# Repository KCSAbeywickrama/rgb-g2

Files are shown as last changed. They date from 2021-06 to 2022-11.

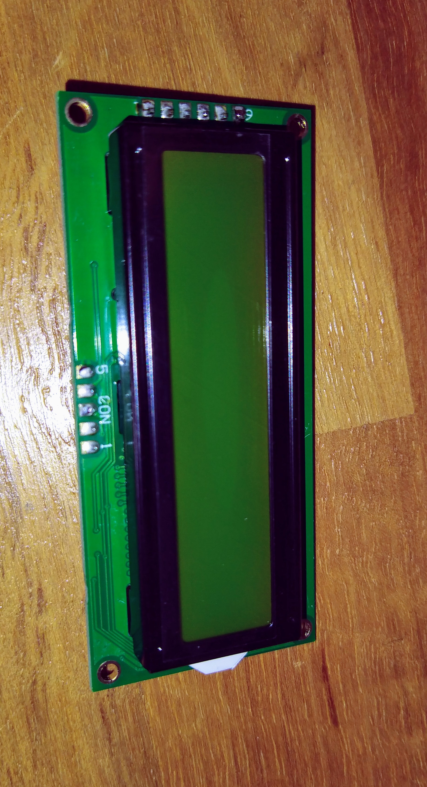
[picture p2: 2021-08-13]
enclosure/external parts/lcd/LCD Module 16x2.jpg

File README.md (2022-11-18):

**LEN1093 Laboratory Practice - I : RGB Color Sensor Project**

A colour sensing device is made using the RGB model approach. This device has three operational modes. Calibration mode, Sensor mode and Given value RGB mode. The calibration mode is to calibrate the device before the test run and this is done in real-time using only three colours. The goal of the Sensor mode is to identify the red, green, blue content in the colour of a given surface and display them using an LCD. In given value RGB mode
a keypad is used to get user inputs and light is illuminated according to those inputs. This colour sensor is developed without using any third-party libraries and only using one PWM pin in the microcontroller to control an RGB LED. We explored different algorithms to achieve high accuracy and finally ended up with a simple endpoint method algorithm. An end product is made including the custom PCB design and a user-friendly 3D enclosure.

**Group Members**

<pre>
+-----------+----------------------+----------------+  
|   Index   |         Name         |    Branches    |  
+-----------+----------------------+----------------+
|  190012X  | Abeysinghe A.L.R     | 12X, enclosure |
|  190014F  | Abeysinghe W.A.M.S.Y | 14F, pcb       |  
|  190018V  | Abeywickrama K.C.S.  | 18V, pcb       |  
|  190021A  | Adikari A.M.A.D.     | 21A, enclosure |  
+-----------+----------------------+----------------+  
</pre>

https://user-images.githubusercontent.com/81417619/202612575-ead0735a-a69e-47e2-82ca-92c3c0942de2.mp4

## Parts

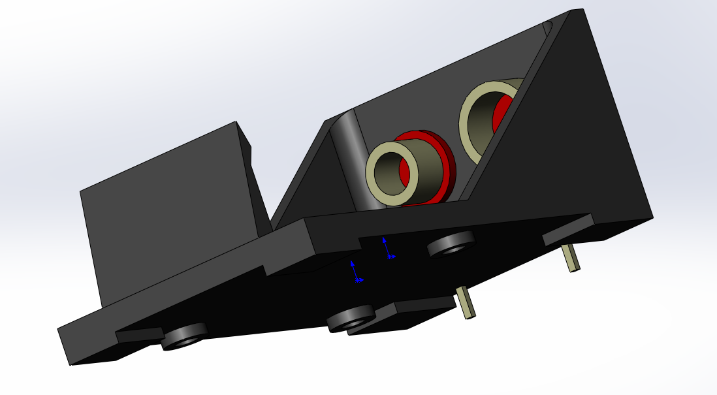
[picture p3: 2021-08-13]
enclosure/external parts/battery holder/Renderings/Безымянный.png

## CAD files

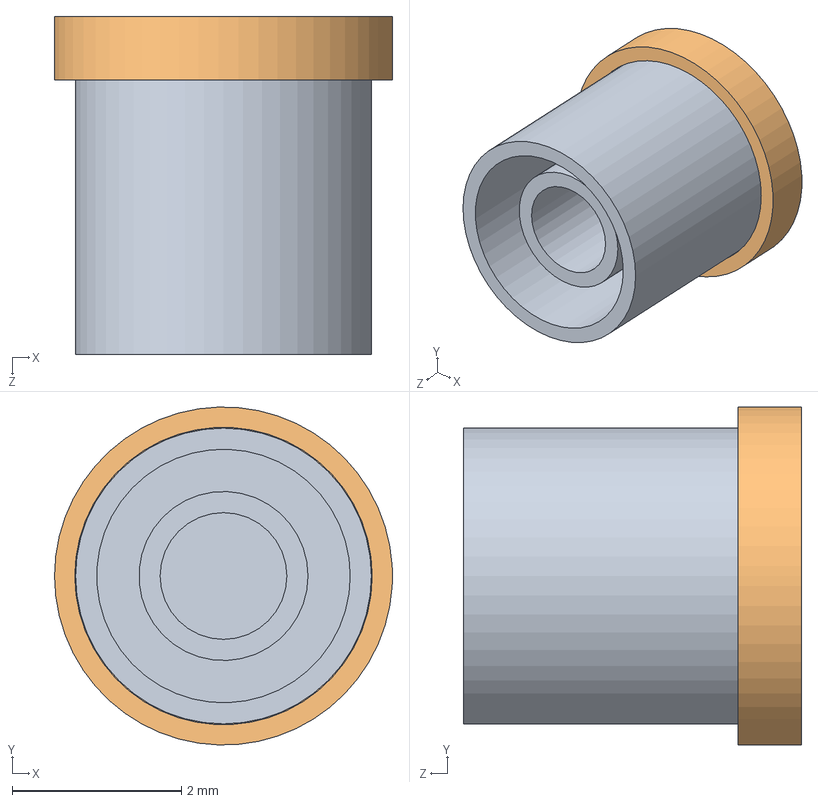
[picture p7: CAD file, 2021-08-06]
enclosure/12X/Sensor_full.SLDASM
4.00 x 4.00 x 4.00 mm
sensor_model_1_p1
sensor_model_1_p2

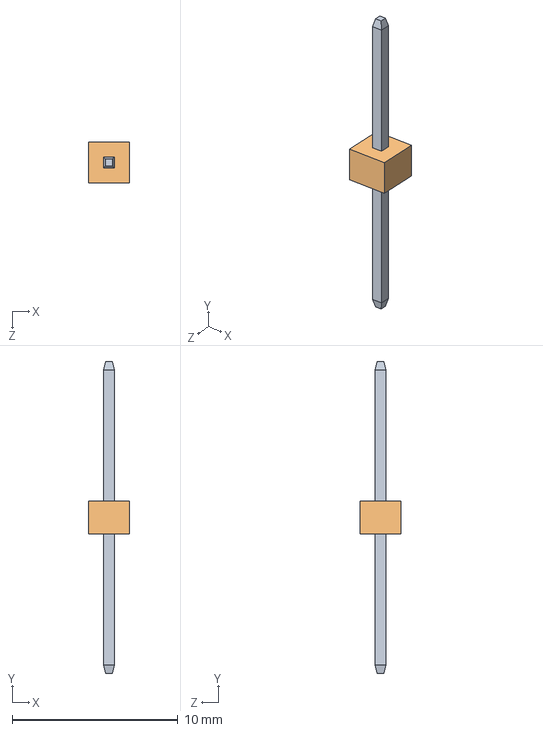
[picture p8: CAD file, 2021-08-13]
enclosure/external parts/jumper/Jumper.SLDASM
2.50 x 18.8 x 2.50 mm
Pin
Socket

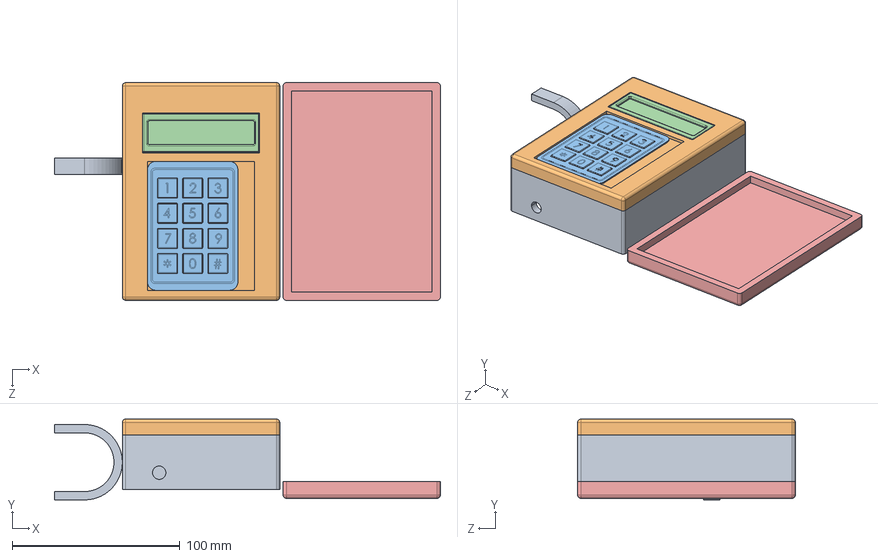
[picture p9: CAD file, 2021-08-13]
enclosure/enclosure parts/enclosure assembly.SLDASM
230.4 x 48.2 x 130.0 mm
middle_from_step
UPPER__FROM_STEP
keypad
LCDScreen
Part1^enclosure assembly

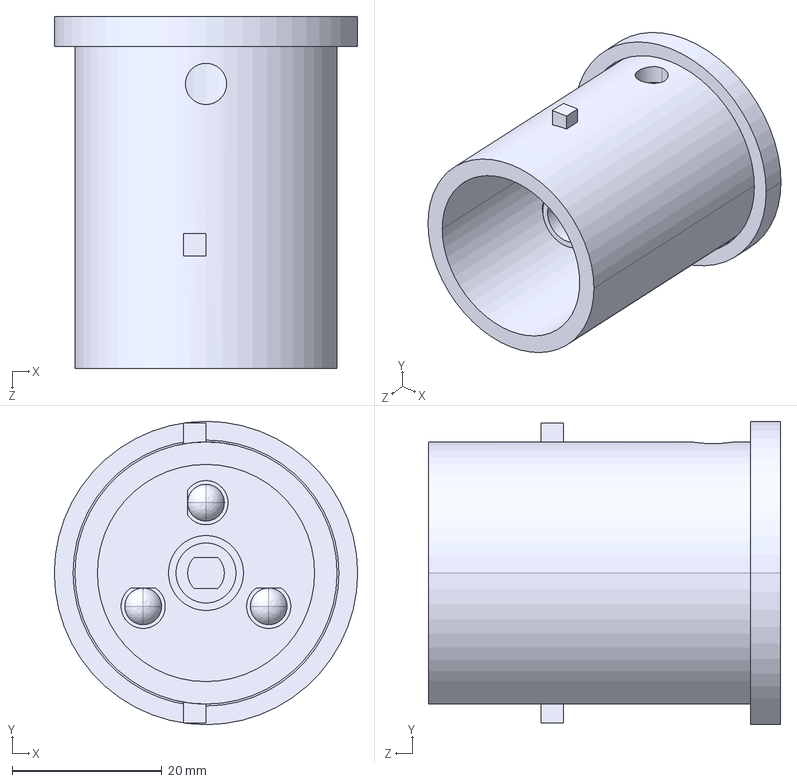
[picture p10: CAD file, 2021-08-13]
enclosure/Sensor/Sensor_full(final).STEP
40.5 x 40.5 x 47.0 mm
sensor_body
Resistor_10K_Ohm_tol1pct_0,25W__07,62.step x 2
LED_5mm_white_TH.step x 3
Extruded.step
Cylinder.step
Cylinder-0.step
Sensor_Top

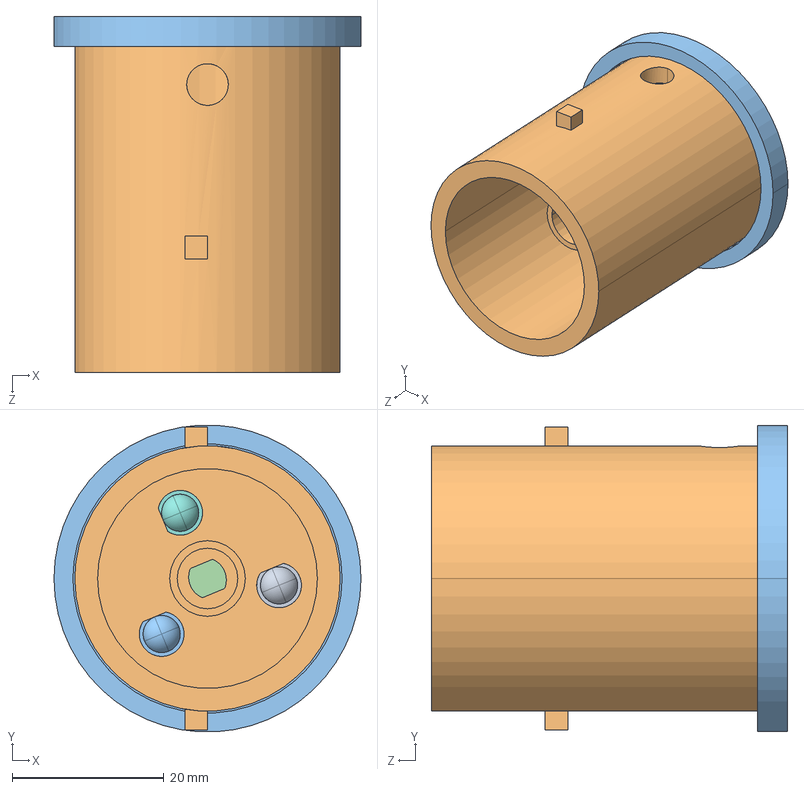
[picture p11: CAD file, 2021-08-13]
enclosure/Sensor/Sensor_full.SLDASM
40.5 x 40.4 x 47.0 mm
Resistor_10K_Ohm_tol1pct_0,25W__07,62.step^R7.step_PCB_Sensor (2).step_Sensor_full (1)_Sensor_full
LED_5mm_white_TH.step^D1.step_PCB_Sensor (2).step_Sensor_full (1)_Sensor_full
Extruded.step^5044068176.step_R9.step_PCB_Sensor (2).step_Sensor_full (1)_Sensor_full
Cylinder.step^6007015744.step_R9.step_PCB_Sensor (2).step_Sensor_full (1)_Sensor_full
Cylinder-0.step^5044512256.step_R9.step_PCB_Sensor (2).step_Sensor_full (1)_Sensor_full
Resistor_10K_Ohm_tol1pct_0,25W__07,62.step^R8.step_PCB_Sensor (2).step_Sensor_full (1)_Sensor_full
LED_5mm_white_TH.step^D3.step_PCB_Sensor (2).step_Sensor_full (1)_Sensor_full
LED_5mm_white_TH.step^D2.step_PCB_Sensor (2).step_Sensor_full (1)_Sensor_full
sensor_body^Sensor_full (1)_Sensor_full
Sensor_Top^Sensor_full (1)_Sensor_full

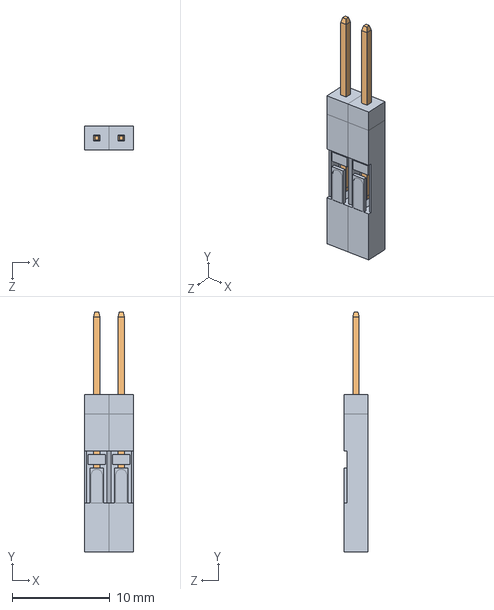
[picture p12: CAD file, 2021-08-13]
enclosure/external parts/jumper/Patterned.SLDASM
5.00 x 24.5 x 2.50 mm
Socket x 4
Pin x 2

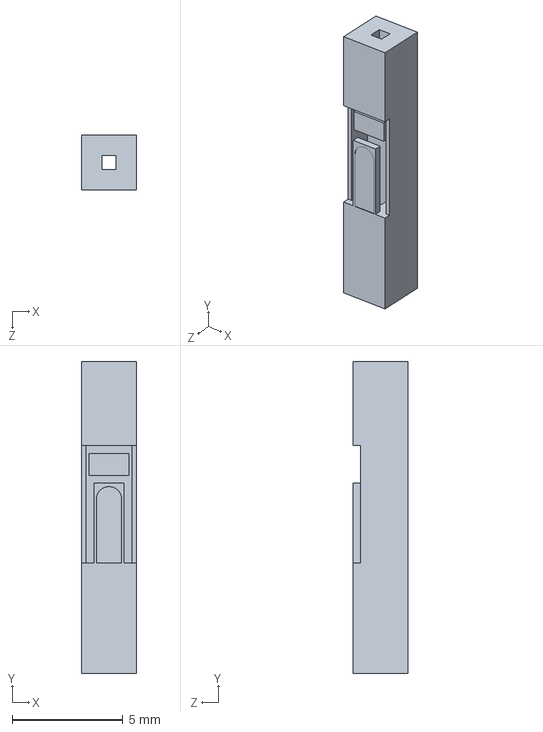
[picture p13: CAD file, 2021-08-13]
enclosure/external parts/jumper/Converted/STEP/Socket_lcd.SLDASM
2.50 x 14.1 x 2.50 mm

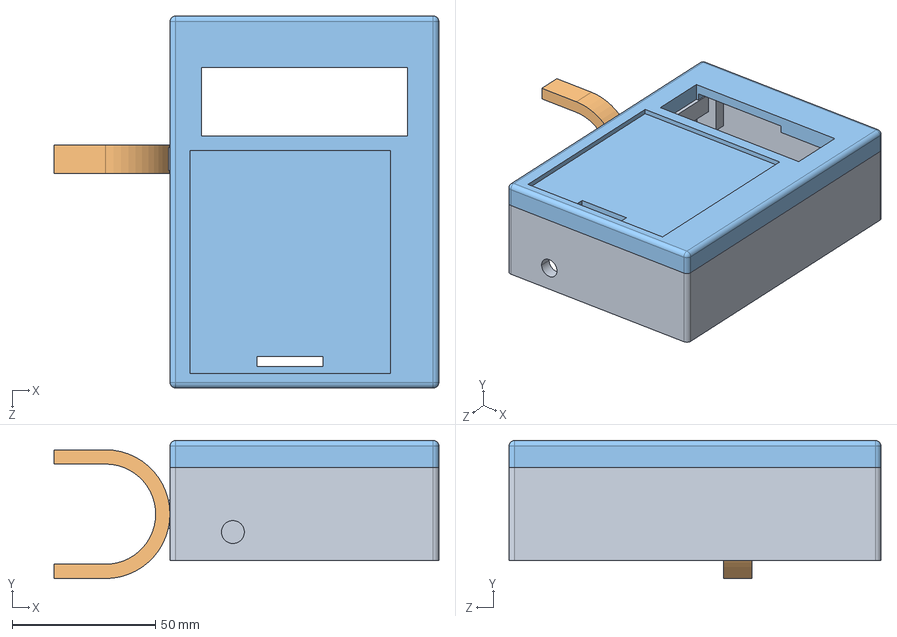
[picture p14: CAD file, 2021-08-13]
enclosure/model_2_assembly(up+mid)_stp.STEP
134.5 x 48.2 x 130.0 mm
Model_2_middle
Model_2_upper

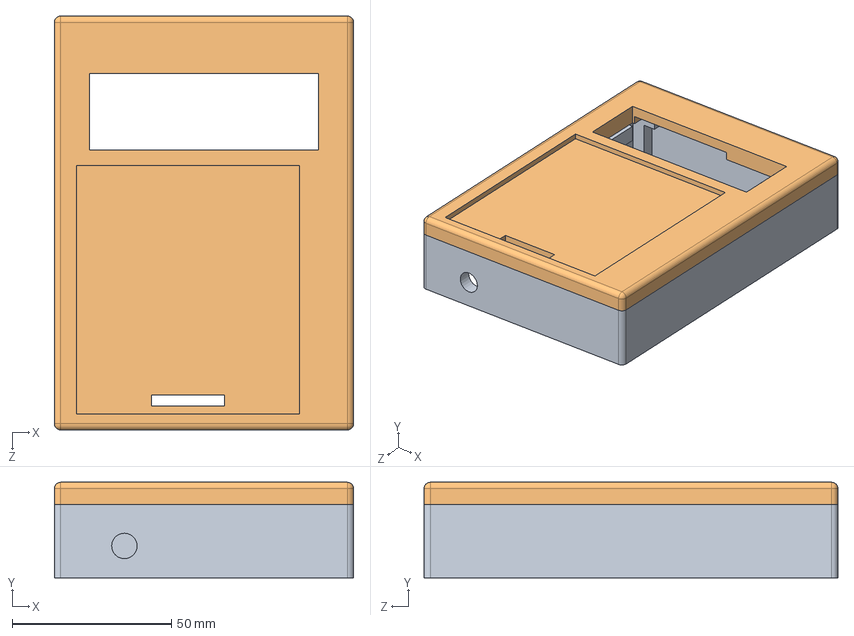
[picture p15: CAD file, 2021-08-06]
enclosure/enclosure_missed/model_2_assembly(up+mid).SLDASM
94.0 x 30.0 x 130.0 mm
Model_2_middle
Model_2_upper

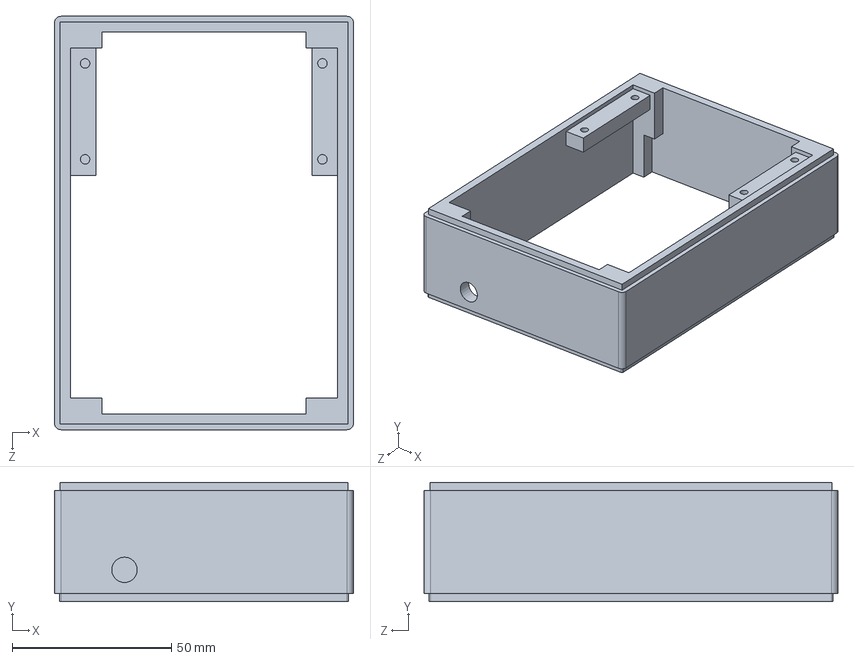
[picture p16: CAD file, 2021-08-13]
enclosure/enclosure parts/middle_without_hanger.SLDPRT
94.0 x 37.5 x 130.0 mm

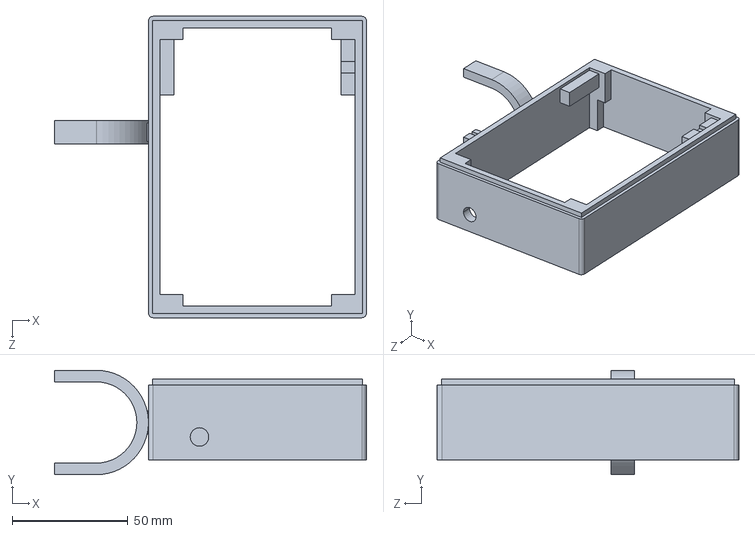
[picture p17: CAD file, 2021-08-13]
enclosure/enclosure_missed/middle_from_step.SLDPRT
134.5 x 45.0 x 130.0 mm

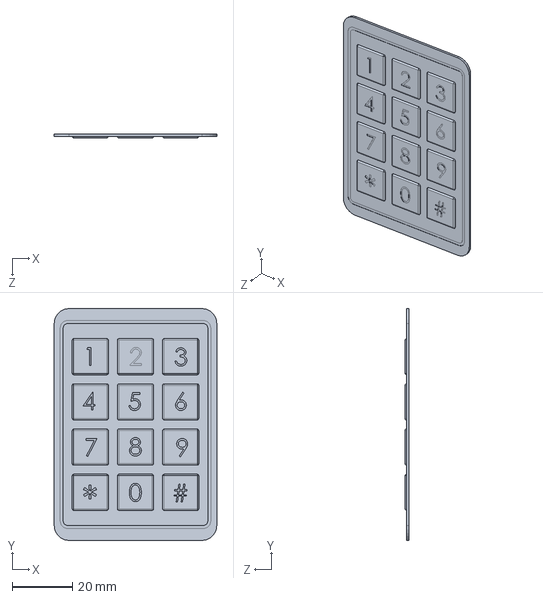
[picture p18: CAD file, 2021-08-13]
enclosure/enclosure_missed/parts/keypad/keypad_noColor.SLDPRT
54.0 x 77.0 x 1.31 mm

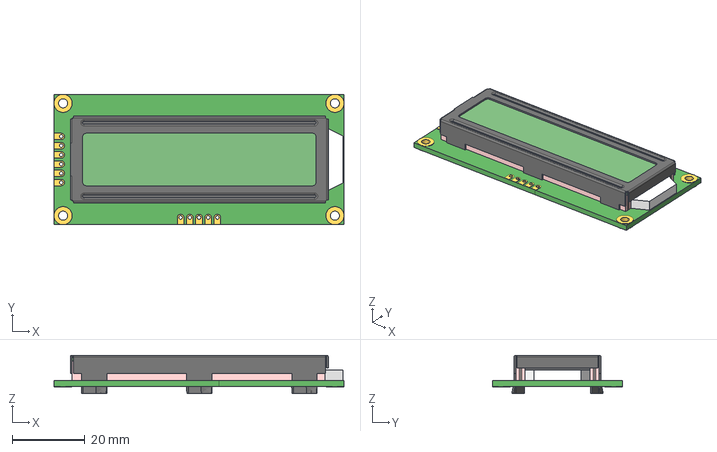
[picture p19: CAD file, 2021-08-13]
enclosure/enclosure_missed/parts/lcd/RSI1602-00.stp
80.0 x 36.0 x 10.6 mm

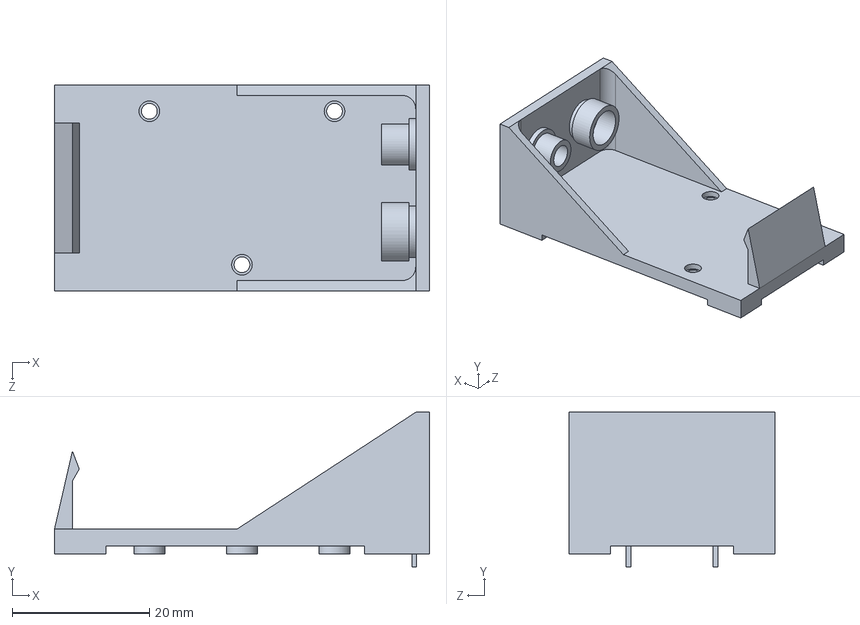
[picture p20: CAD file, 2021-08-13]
enclosure/external parts/battery holder/BATTARY HOLDER.STEP
54.6 x 22.5 x 30.0 mm

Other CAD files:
enclosure/Sensor/Sensor_full (1).STEP
enclosure/12X/sensor_model_1_p1.SLDPRT
enclosure/12X/sensor_model_1_p2.SLDPRT
enclosure/21A_upper.SLDPRT
enclosure/Model_2_middle.SLDPRT
enclosure/Model_2_middle_stp.STEP
enclosure/Model_2_upper.SLDPRT
enclosure/Model_2_upper_stp.STEP
enclosure/Sensor/PCB_Sensor (2).step
enclosure/Sensor/Sensor_Top.STEP
enclosure/Sensor/Sensor_full(final).SLDASM
enclosure/Sensor/sensor_body.STEP
enclosure/enclosure parts/Model_2_middle.SLDPRT
enclosure/enclosure parts/Model_2_upper.SLDPRT
enclosure/enclosure parts/UPPER__FROM_STEP.SLDPRT
enclosure/enclosure parts/bottom_part.SLDPRT
enclosure/enclosure parts/circular_leg.SLDPRT
enclosure/enclosure parts/middle_from_step.SLDPRT
enclosure/enclosure parts/middle_part_from_step.x_t
enclosure/enclosure parts/model_1.SLDPRT
enclosure/enclosure parts/sensor_closer.SLDPRT
enclosure/enclosure parts/sensor_model1.SLDPRT
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

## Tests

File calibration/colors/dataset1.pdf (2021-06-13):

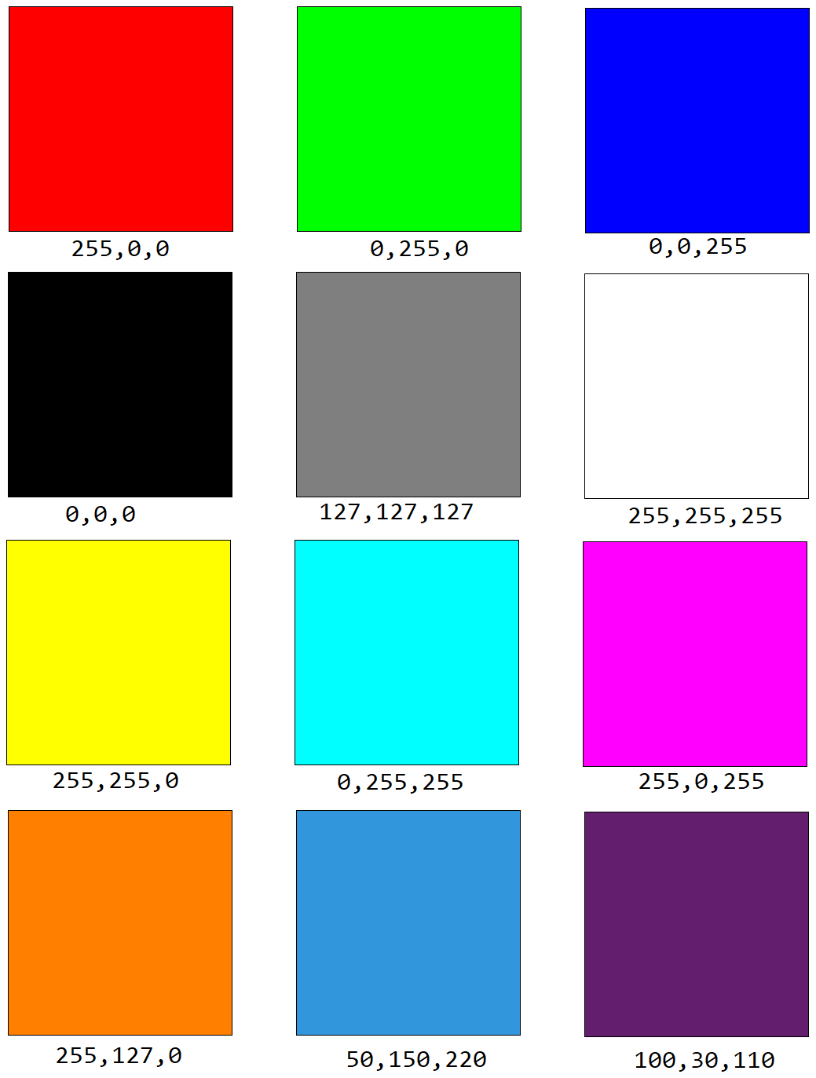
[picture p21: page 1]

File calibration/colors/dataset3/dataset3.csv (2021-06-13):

r | g | b | r | g | r | "-b" | "-b" | g
255 | 255 | 255 | 255 | 255 | 255 | -255 | -255 | 255
0 | 0 | 0 | 0 | 0 | 0 | 0 | 0 | 0
255 | 0 | 0 | 255 | 0 | 255 | 0 | 0 | 0
0 | 255 | 0 | 0 | 255 | 0 | 0 | 0 | 255
0 | 0 | 255 | 0 | 0 | 0 | -255 | -255 | 0
255 | 192 | 192 | 255 | 192 | 255 | -192 | -192 | 192
255 | 128 | 128 | 255 | 128 | 255 | -128 | -128 | 128
255 | 64 | 64 | 255 | 64 | 255 | -64 | -64 | 64
204 | 0 | 0 | 204 | 0 | 204 | 0 | 0 | 0
153 | 0 | 0 | 153 | 0 | 153 | 0 | 0 | 0
102 | 0 | 0 | 102 | 0 | 102 | 0 | 0 | 0
51 | 0 | 0 | 51 | 0 | 51 | 0 | 0 | 0
192 | 255 | 192 | 192 | 255 | 192 | -192 | -192 | 255
128 | 255 | 128 | 128 | 255 | 128 | -128 | -128 | 255
64 | 255 | 64 | 64 | 255 | 64 | -64 | -64 | 255
0 | 204 | 0 | 0 | 204 | 0 | 0 | 0 | 204
0 | 153 | 0 | 0 | 153 | 0 | 0 | 0 | 153
0 | 102 | 0 | 0 | 102 | 0 | 0 | 0 | 102
0 | 51 | 0 | 0 | 51 | 0 | 0 | 0 | 51
192 | 192 | 255 | 192 | 192 | 192 | -255 | -255 | 192
128 | 128 | 255 | 128 | 128 | 128 | -255 | -255 | 128
64 | 64 | 255 | 64 | 64 | 64 | -255 | -255 | 64
0 | 0 | 204 | 0 | 0 | 0 | -204 | -204 | 0
0 | 0 | 153 | 0 | 0 | 0 | -153 | -153 | 0
0 | 0 | 102 | 0 | 0 | 0 | -102 | -102 | 0
0 | 0 | 51 | 0 | 0 | 0 | -51 | -51 | 0
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

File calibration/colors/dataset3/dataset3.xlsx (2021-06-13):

r | g | b | r | g | r | "-b" | "-b" | g
255 | 255 | 255 | 255 | 255 | 255 | -255 | -255 | 255
0 | 0 | 0 | 0 | 0 | 0 | 0 | 0 | 0
255 | 0 | 0 | 255 | 0 | 255 | 0 | 0 | 0
0 | 255 | 0 | 0 | 255 | 0 | 0 | 0 | 255
0 | 0 | 255 | 0 | 0 | 0 | -255 | -255 | 0
255 | 192 | 192 | 255 | 192 | 255 | -192 | -192 | 192
255 | 128 | 128 | 255 | 128 | 255 | -128 | -128 | 128
255 | 64 | 64 | 255 | 64 | 255 | -64 | -64 | 64
204 | 0 | 0 | 204 | 0 | 204 | 0 | 0 | 0
153 | 0 | 0 | 153 | 0 | 153 | 0 | 0 | 0
102 | 0 | 0 | 102 | 0 | 102 | 0 | 0 | 0
51 | 0 | 0 | 51 | 0 | 51 | 0 | 0 | 0
192 | 255 | 192 | 192 | 255 | 192 | -192 | -192 | 255
128 | 255 | 128 | 128 | 255 | 128 | -128 | -128 | 255
64 | 255 | 64 | 64 | 255 | 64 | -64 | -64 | 255
0 | 204 | 0 | 0 | 204 | 0 | 0 | 0 | 204
0 | 153 | 0 | 0 | 153 | 0 | 0 | 0 | 153
0 | 102 | 0 | 0 | 102 | 0 | 0 | 0 | 102
0 | 51 | 0 | 0 | 51 | 0 | 0 | 0 | 51
192 | 192 | 255 | 192 | 192 | 192 | -255 | -255 | 192
128 | 128 | 255 | 128 | 128 | 128 | -255 | -255 | 128
64 | 64 | 255 | 64 | 64 | 64 | -255 | -255 | 64
0 | 0 | 204 | 0 | 0 | 0 | -204 | -204 | 0
0 | 0 | 153 | 0 | 0 | 0 | -153 | -153 | 0
0 | 0 | 102 | 0 | 0 | 0 | -102 | -102 | 0
0 | 0 | 51 | 0 | 0 | 0 | -51 | -51 | 0
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

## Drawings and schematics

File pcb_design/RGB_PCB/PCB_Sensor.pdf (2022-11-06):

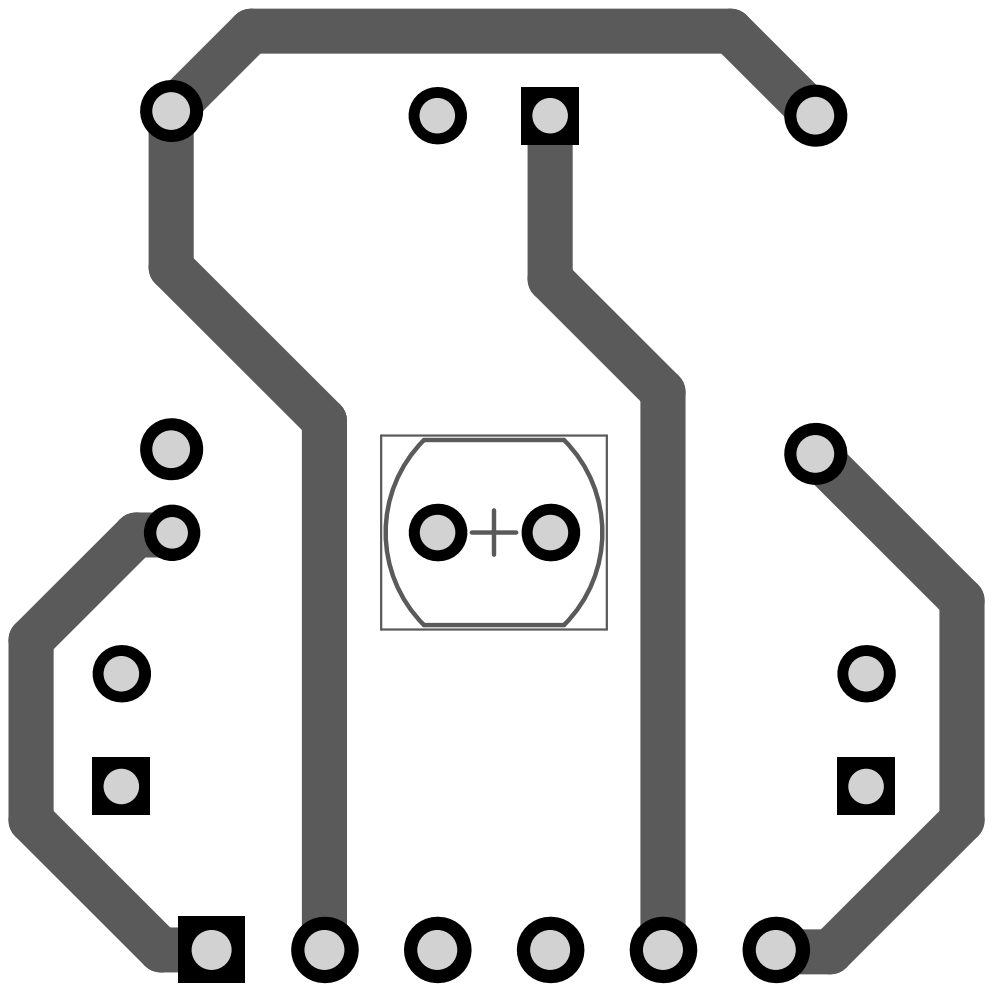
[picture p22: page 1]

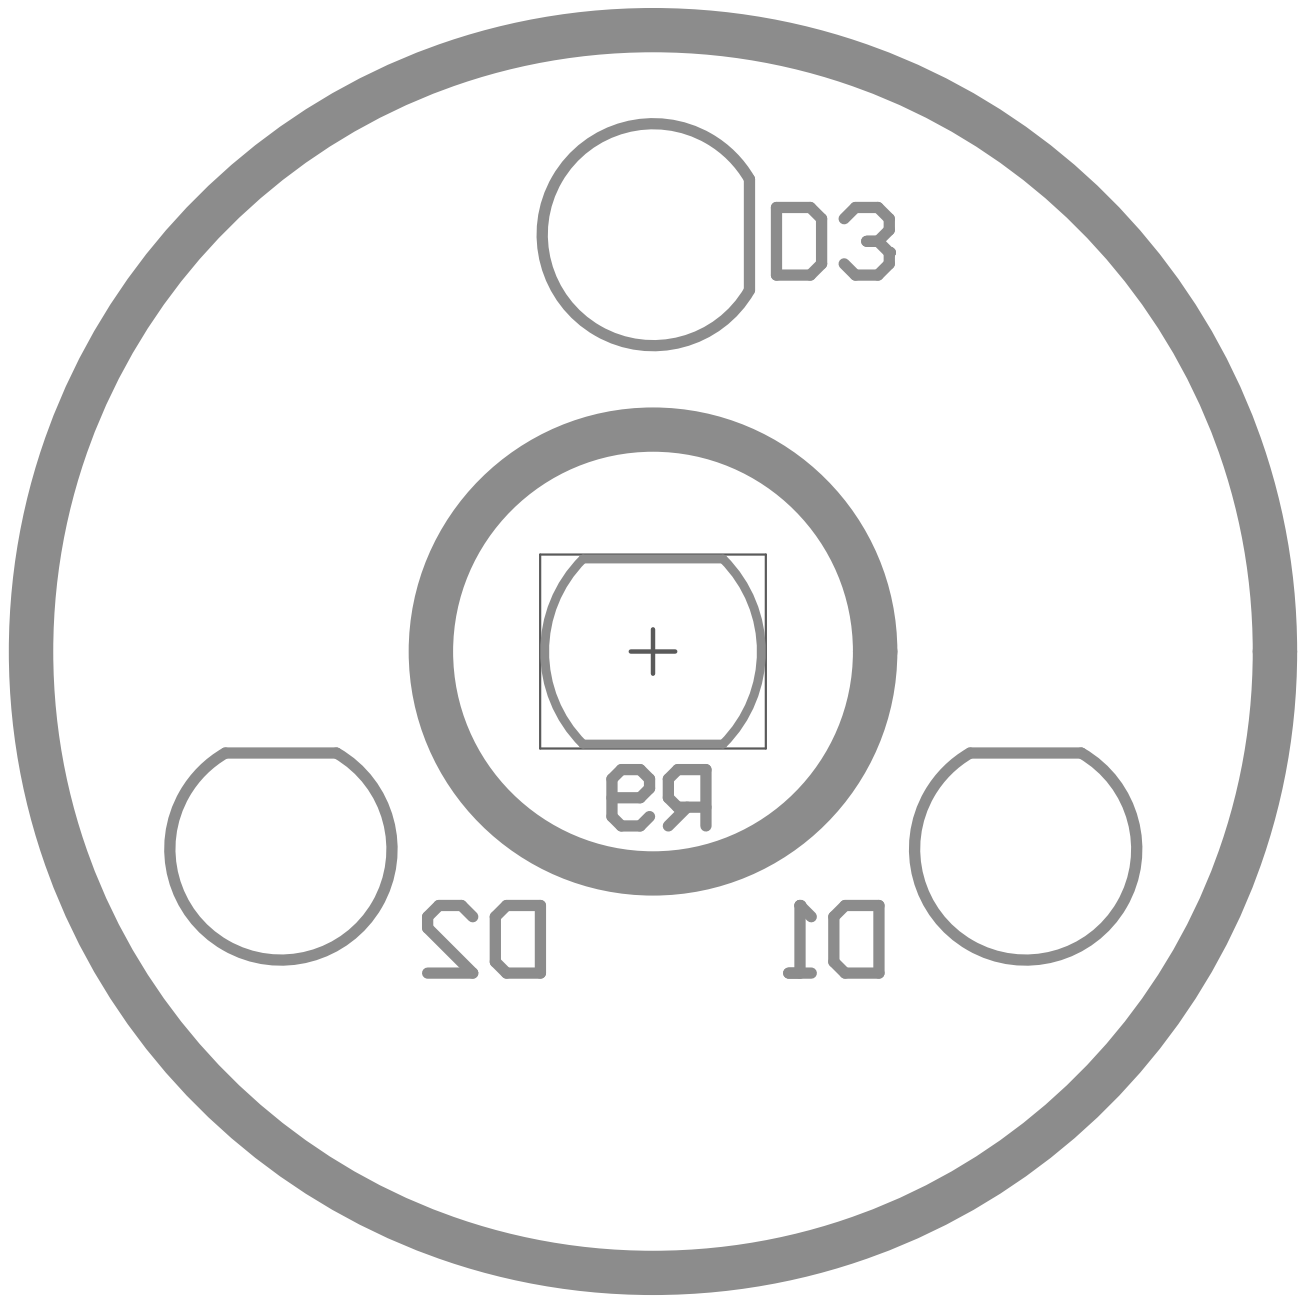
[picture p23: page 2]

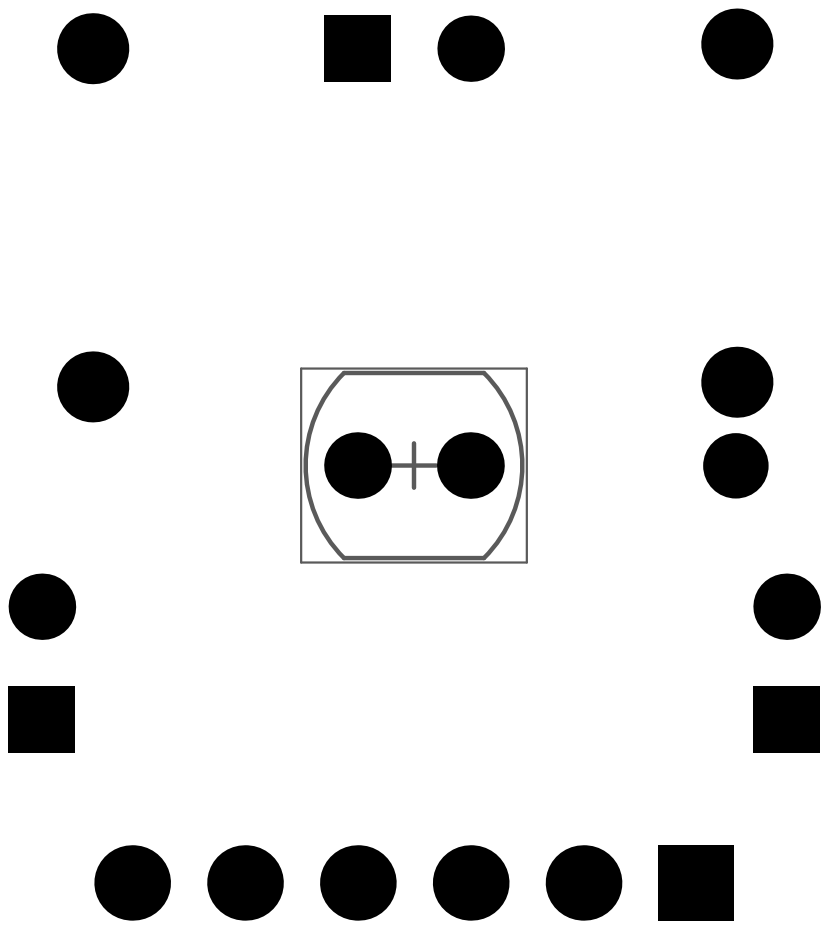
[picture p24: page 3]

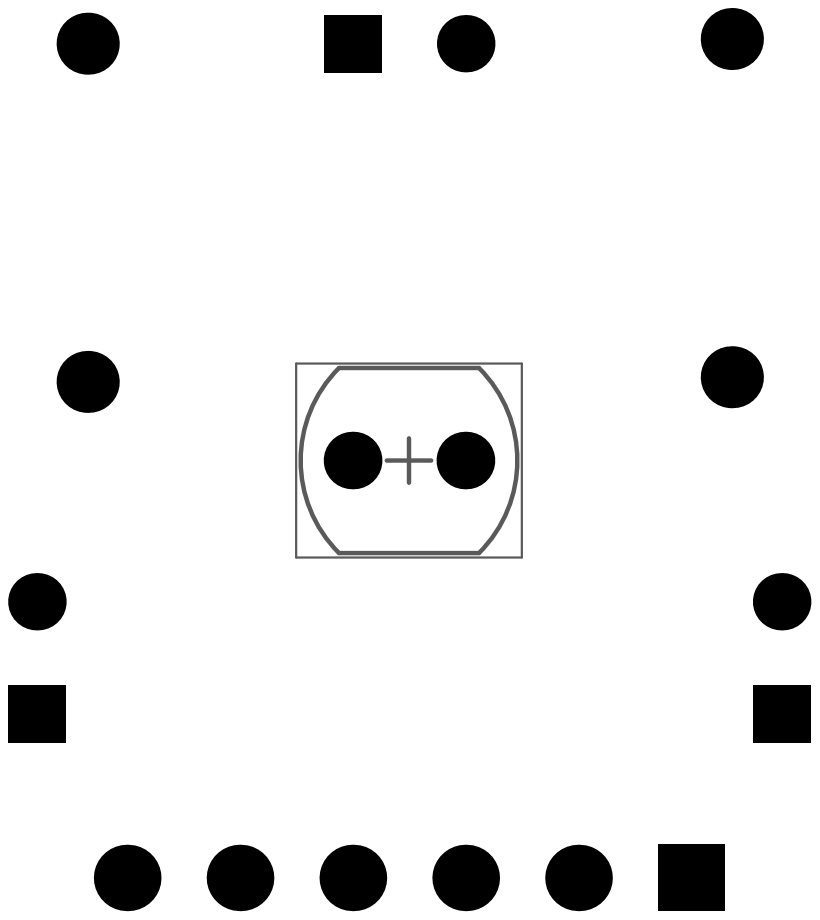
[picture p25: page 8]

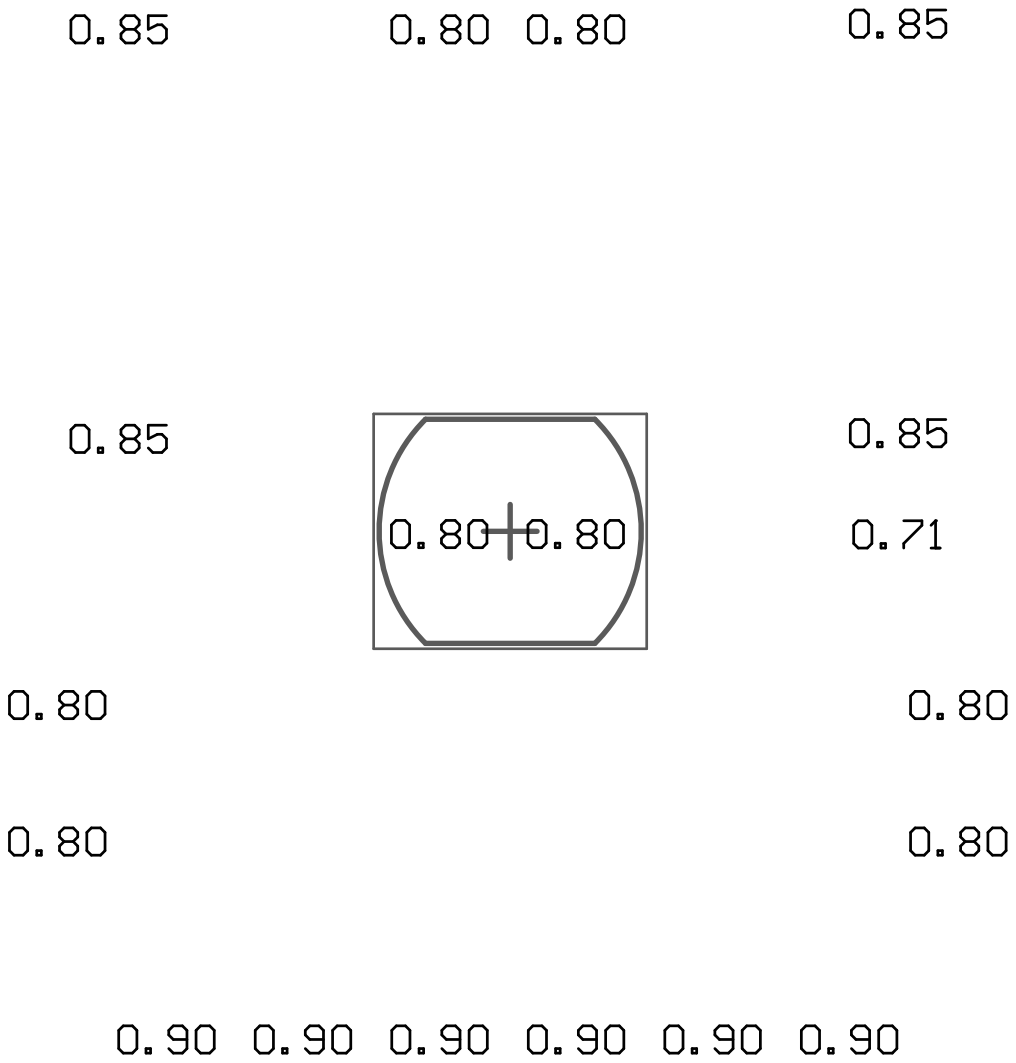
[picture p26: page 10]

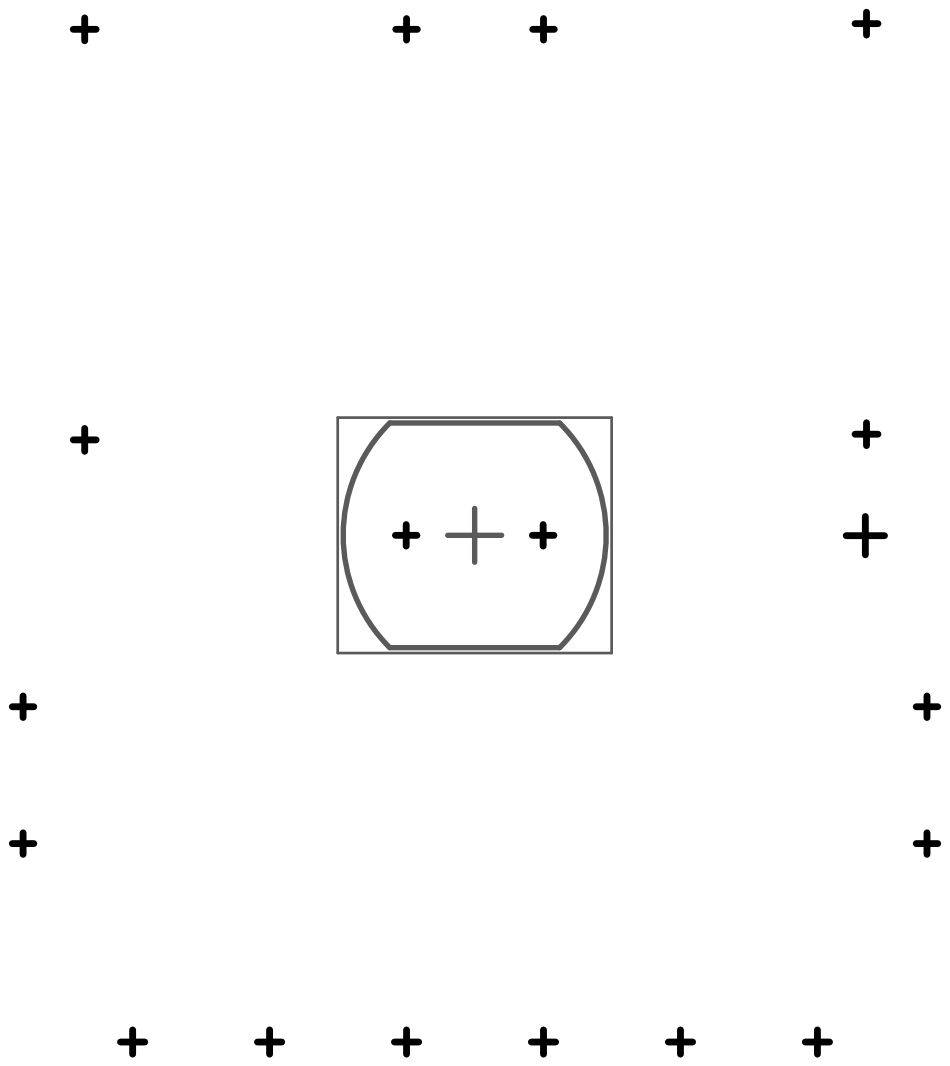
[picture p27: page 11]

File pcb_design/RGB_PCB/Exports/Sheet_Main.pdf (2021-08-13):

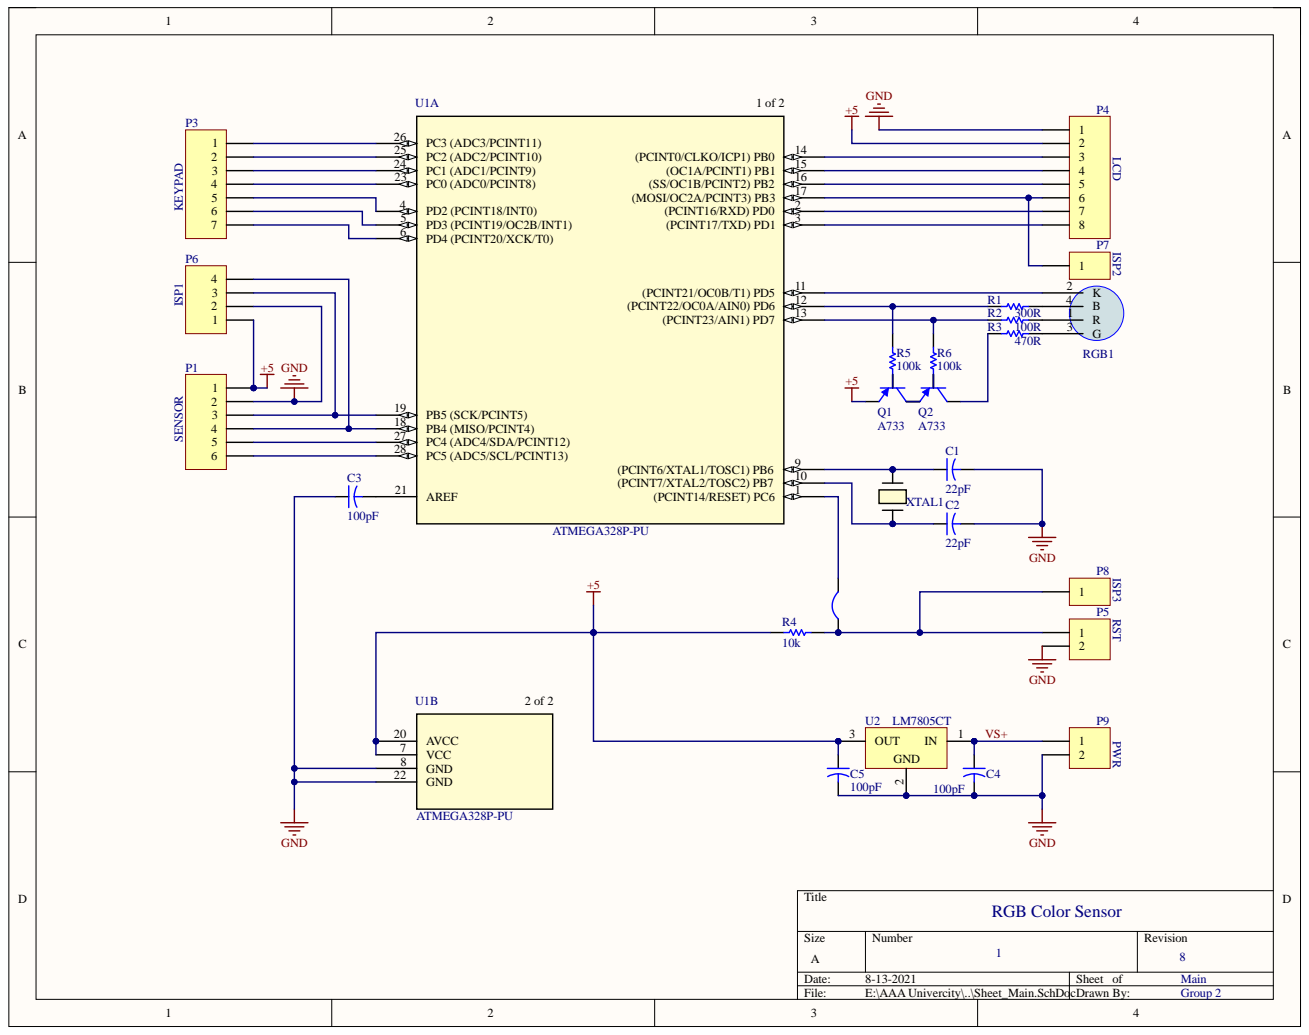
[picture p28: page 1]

PB4 (MISO/PCINT4) 18 PB5 (SCK/PCINT5) 19

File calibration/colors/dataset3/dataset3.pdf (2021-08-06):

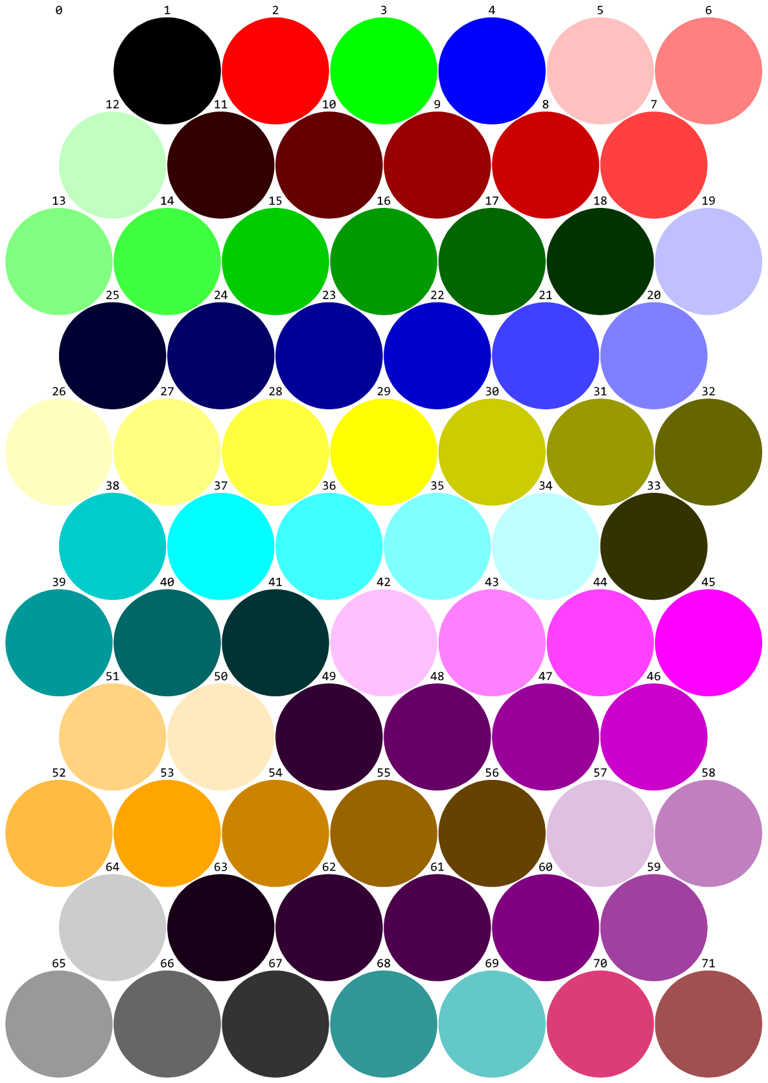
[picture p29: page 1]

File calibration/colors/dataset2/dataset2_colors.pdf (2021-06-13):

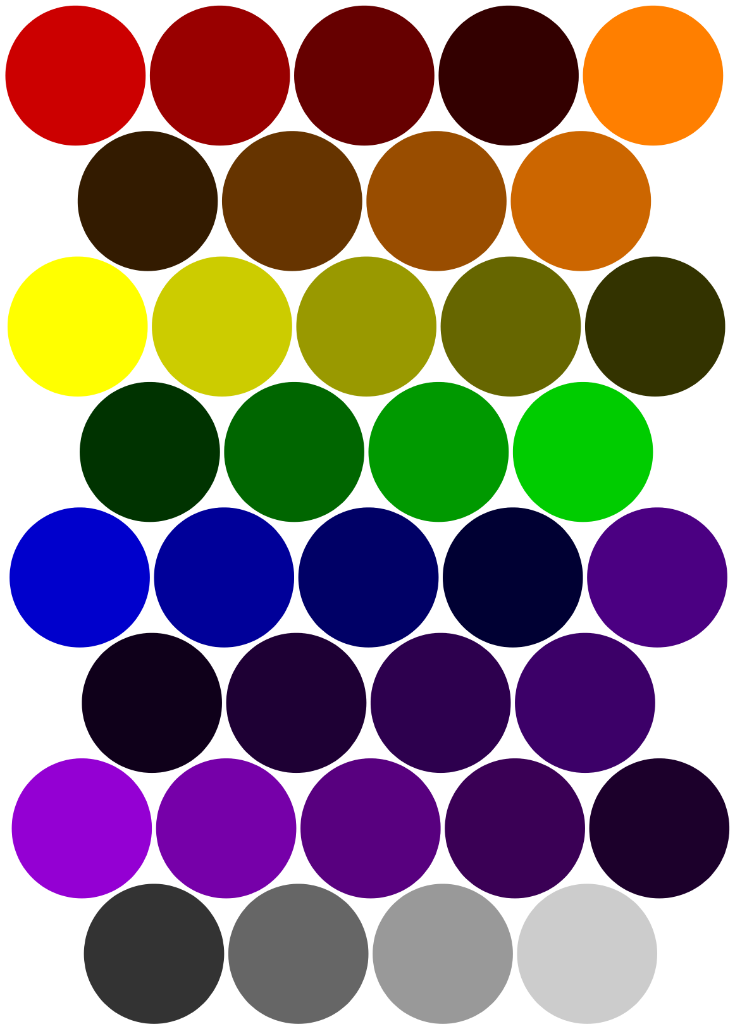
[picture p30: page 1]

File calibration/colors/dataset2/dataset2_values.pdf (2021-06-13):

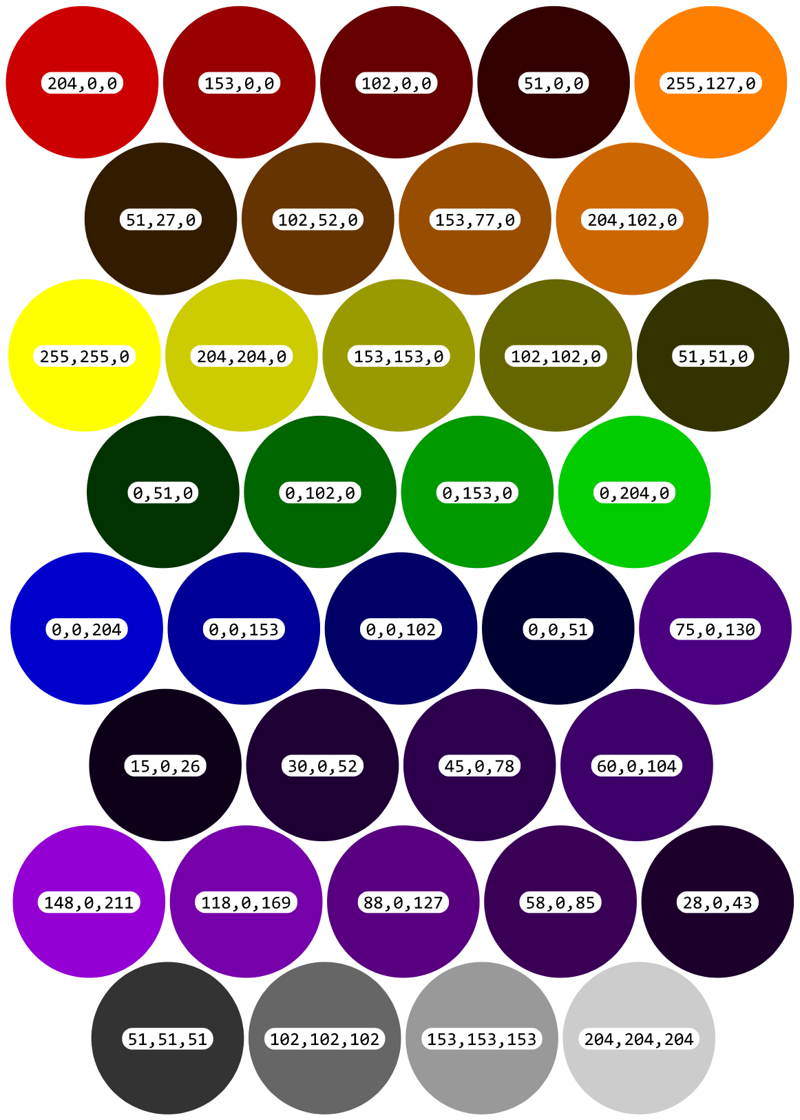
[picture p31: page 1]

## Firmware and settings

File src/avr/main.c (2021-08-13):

/*
* main.c
*
* Created: 6/12/2021 11:27:28 PM
* Author : Dulanjana
*/

#define F_CPU 16000000UL

#include <avr/io.h>
#include <util/delay.h>
#include "cores/lcd.h"
#include "cores/keypad.h"
#include "cores/pwm.h"
#include "cores/calib.h"
#include "cores/sensor.h"

uint16_t reading[3]; //sensor readings
uint8_t rgb[3];		 //rgb values
char *rgb_str[3]={"RED = ","GREEN = ","BLUE = "};

//declaring fucnitons for modes
void sensor_mode();
void calib_mode();
void read_mode();
void rgb_mode();


int main(void)
{
	//init cores
	lcd_init();	
	keypad_init();
	sensor_init();
	pwm_init();
	
	//display a startup message
	lcd_clear();
	lcd_string("RGB Color Sensor");
	lcd_set_cursor(1,4);
	lcd_string("Group 2");
	_delay_ms(3000);	
	
	while (1){

		//display the main menu
		lcd_clear();
		lcd_set_cursor(0,0);
		lcd_string("1 - Color Sensor");	
		lcd_set_cursor(1,0);
		lcd_string("2 - Given RGB");

		//get the input key to select options from main menu
		char mainmenu_key=keypad_get_key();
		
		//key1: goto color sensor mode
		if (mainmenu_key=='1')sensor_mode();

		//key2: goto given value RGB mode
		else if (mainmenu_key=='2')rgb_mode();
		
		//debounce delay
		_delay_ms(300);
	}
}

void calib_mode(){		
	lcd_clear();
	lcd_set_cursor(0,2);
	lcd_string("Calibration");
	lcd_set_cursor(1,4);
	lcd_string("Started");
	_delay_ms(2000);

	//start calibration for colors
	calib_start();	
	
	lcd_clear();
	lcd_set_cursor(0,2);
	lcd_string("Calibration");
	lcd_set_cursor(1,5);
	lcd_string("Done");
	_delay_ms(2000);
}

void read_mode(){
	
	while (1)
	{
		lcd_clear();				
		lcd_string("Place on color");
		lcd_string_blink("...Waiting...",2,1,1);		
		
		//get readings and calculate the color
		sensor_read(reading);
		calib_calc(reading,rgb);

		//display color code
		lcd_clear();
		lcd_set_cursor(0,2);
		lcd_string("@ ");
		lcd_uint8_arr(rgb);
		lcd_set_cursor(1,0);
		lcd_string("Menu=<-  Read=->");

		//ligt up RGB led with respective color
		pwm_set(rgb);
		pwm_start();

		//ask for continue or stop 		
		while (1){
			char con_key=keypad_get_key();
			if (con_key==OK_KEY){
				pwm_stop();
				break;
			}
			if(con_key==BACK_KEY){
				pwm_stop();
				_delay_ms(300);
				return;
			}
		}
	}
	
}

void sensor_mode(){
	
	lcd_clear();
	lcd_set_cursor(0,2);
	lcd_string("Color Sensor");
	_delay_ms(2000);

	while (1){

		//display a menu for calibrating or reading color values
		lcd_clear();
		lcd_set_cursor(0,0);
		lcd_string("1-Calib   2-Read");
		lcd_set_cursor(1,5);
		lcd_string("Menu=<-");

		char value='\0';
		while(value=='\0'){
			value=keypad_get_key();
			
			if (value==BACK_KEY){
				_delay_ms(300);
				break;
			}

			//key1: goto calibraiton mode
			else if (value=='1') calib_mode();
			
			//key2: goto color reading mode
			else if (value=='2') read_mode();
		}

		//back key: exit from sensor mode
		if (value==BACK_KEY){
			break;
		}
	}
}

void rgb_input(){
	//display a message to enter values
	lcd_clear();
	lcd_set_cursor(0,0);
	lcd_string("Enter values");

	//get RGB values
	for (int color=0;color<3;color++){
		lcd_clear_line(1);
		lcd_string(rgb_str[color]);		//display the color name
		
		
		int rgb_value=0;	//given value
		int len_value=0;	//length of the input value
		
		while(1){
			char key=keypad_get_key();

			//break and go to next color
			if (key==OK_KEY){
				_delay_ms(300);
				break;
			}

			//delete a wrong input character
			else if (key==BACK_KEY){
				if (len_value){
					lcd_delete();
					_delay_ms(300);
					rgb_value/=10;
					len_value-=1;
				}
			}

			else{
				//display pressed key on lcd display
				lcd_char(key);			
				_delay_ms(300);

				//calculate the integer value from pressed keys
				rgb_value=rgb_value*10+(key-'0');
				len_value+=1;
			}
		}

		//check whether the entered value is valid
		if (rgb_value>255){
			lcd_clear();
			lcd_set_cursor(0,2);
			lcd_string("Invalid input");
			_delay_ms(2000);

			//if the value is invalid allow to enter that value again
			lcd_clear();
			lcd_set_cursor(0,0);
			lcd_string("Enter values");
			color-=1;
		}

		//if inputs are OK, then add them to the rgb array
		else{
			rgb[color]=rgb_value;
		}
	}
}


void rgb_mode(){
	
	lcd_clear();
	lcd_set_cursor(0,2);
	lcd_string("Given Value");
	lcd_set_cursor(1,6);
	lcd_string("RGB");
	_delay_ms(2000);

	while(1){
		
		//get rgb color code input
		rgb_input();

		//display the entered color values
		lcd_clear();
		lcd_set_cursor(0,2);
		lcd_string("@ ");
		lcd_uint8_arr(rgb);
		lcd_set_cursor(1,0);
		lcd_string("Menu=<-   RGB=->");
		
		//ligt up RGB led with the enterd color
		pwm_set(rgb);
		pwm_start();

		//ask for continue with this mode or go back to menu
		char con_key;
		while (1){
			con_key=keypad_get_key();
			if (con_key==OK_KEY || con_key==BACK_KEY){
				break;
			}
		}

		//exit from given value rgb mode
		if(con_key==BACK_KEY){		
			pwm_stop();
			break;
		}
		
		//debounce delay
		_delay_ms(300);
	}
}

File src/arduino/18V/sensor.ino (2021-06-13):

byte sensorLeds[3] = {A3, A4, A5};
byte sensorLdr = A2;
int i = 0;
int readings[3] = {0, 0, 0};
int colors[3] = {0, 0, 0};

int calibColors[5][3] = {{255, 0, 0}, {0, 255, 0}, {0, 0, 255}, {0, 0, 0}, {255, 255, 255}};
int calibData[5][3] = {{655, 120, 121}, {399, 233, 124}, {296, 156, 211}, {295, 94, 95}, {658, 335, 306}};
int calibConst[3][2];

void initSensor()
{
    pinMode(13, OUTPUT);
    for (byte pin : sensorLeds)
        pinMode(pin, OUTPUT);
}

unsigned int analogLastRead(byte pin, byte samples)
{
    unsigned int value;
    for (int i = 0; i < samples; i++)
    {
        delay(100);
        value = analogRead(pin);
        //     Serial.print(value);
        //     Serial.print('.');
    }
    // Serial.println();
    return value;
}

void readSensor(int *readings)
{
    // Serial.println("Reading . . .");

    for (int i = 0; i < 3; i++)
    {
        digitalWrite(sensorLeds[i], 1);
        readings[i] = analogLastRead(sensorLdr, 20);
        digitalWrite(sensorLeds[i], 0);
    }

    // Serial.println("Readings");
    printTriplet(readings);
}

void showReadings()
{

    readSensor(readings);

    readSensor(readings);
    readSensor(readings);
    Serial.println("Delay");
    delay(100);
    readSensor(readings);
    delay(500);
    readSensor(readings);
    delay(1000);
    readSensor(readings);
    delay(2000);
    readSensor(readings);
    delay(5000);
    readSensor(readings);
    Serial.println("end");
}

void warm()
{
    for (int i = 0; i < 3; i++)
    {
        digitalWrite(sensorLeds[i], 1);
        delay(200);
        int j = analogLastRead(sensorLdr, 30);
        digitalWrite(sensorLeds[i], 0);
    }
}

void blink()
{
    for (int i = 0; i < 5; i++)
    {
        digitalWrite(13, 1);
        delay(500);
        digitalWrite(13, 0);
        delay(500);
    }
}

void readCalibData()
{
    Serial.println("Place on White");
    blink();
    readSensor(calibData[0]);
    Serial.println("calibData[0]");
    printTriplet(calibData[0]);

    Serial.println("\nPlace on Black");
    blink();
    readSensor(calibData[1]);
    Serial.println("calibData[1]");
    printTriplet(calibData[1]);
}

void calc(int *readings, int *colors)
{
    for (int i = 0; i < 3; i++)
    {
        colors[i] = (float)(readings[i] - calibData[1][i]) / (calibData[0][i] - calibData[1][i]) * 255;
        if (colors[i] > 255)
            colors[i] = 255;
        else if (colors[i] < 0)
            colors[i] = 0;
    }
}

void readColors()
{
    Serial.println("Place...");
    delay(4000);
    readSensor(readings);
    calc(readings, colors);
    sendToColorDisp(colors);
}

void sendToColorDisp(int *colors)
{
    for (int i = 0; i < 3; i++)
    {
        Serial.print(colors[i]);
        Serial.print(",");
    }
    Serial.println(" ");
    Serial.println("---------");
}

void printTriplet(int *triplet)
{
    Serial.print(triplet[0]);
    Serial.print(',');
    Serial.print(triplet[1]);
    Serial.print(',');
    Serial.print(triplet[2]);
    Serial.println();
}

void showDataset(int dataset[][3], int from, int to)
{
    for (int i = from; i < to; i++)
    {
        printTriplet(dataset[i]);
        blink();
        readSensor(readings);
        Serial.println();
    }
}

void showDataset1()
{
    int dataset1[][3] = {
        {255, 0, 0},
        {0, 255, 0},
        {0, 0, 255},
        {0, 0, 0},
        {127, 127, 127},
        {255, 255, 255},
        {255, 255, 0},
        {0, 255, 255},
        {255, 0, 255},
        {255, 127, 0},
        {50, 150, 220},
        {100, 30, 110}};

    showDataset(dataset1, 0, 12);
}

void showDataset2()
{
    int dataset2[][3]{
        {204, 0, 0},
        {153, 0, 0},
        {102, 0, 0},
        {51, 0, 0},
        {255, 127, 0},
        {204, 102, 0},
        {153, 77, 0},
        {102, 52, 0},
        {51, 27, 0},
        {255, 255, 0},
        {204, 204, 0},
        {153, 153, 0},
        {102, 102, 0},
        {51, 51, 0},
        {0, 204, 0},
        {0, 153, 0},
        {0, 102, 0},
        {0, 51, 0},
        {0, 0, 204},
        {0, 0, 153},
        {0, 0, 102},
        {0, 0, 51},
        {75, 0, 130},
        {60, 0, 104},
        {45, 0, 78},
        {30, 0, 52},
        {15, 0, 26},
        {148, 0, 211},
        {118, 0, 169},
        {88, 0, 127},
        {58, 0, 85},
        {28, 0, 43},
        {204, 204, 204},
        {153, 153, 153},
        {102, 102, 102},
        {51, 51, 51},
    };

    for (int i = 0; i < 36; i += 9)
    {
        Serial.println(i / 9);
        showDataset(dataset2, i,i+9);
    }
}

void stableCheck()
{
    for (int led = 0; led < 3; led++)
    {
        Serial.println(led);
        digitalWrite(sensorLeds[led], 1);
        for (int time = 0; time < 5000; time += 100)
        {
            String data = String(time) + "," + String(analogRead(sensorLdr) * 10);
            Serial.println(data);
            delay(100);
        }
        digitalWrite(sensorLeds[led], 0);
        delay(3000);
    }
}

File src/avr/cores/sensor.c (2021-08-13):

/*
 * sensor.c
 *
 * Created: 19/05/2021 03:18:54
 *  Author: Lakdilu
 */

#define F_CPU 16000000UL

#include <avr/io.h>
#include <util/delay.h>
#include "sensor.h"
#include "lcd.h"

#define LDR_PIN 5

volatile uint8_t *led_ddrs[3] = {&DDRC, &DDRB, &DDRB};
volatile uint8_t *led_ports[3] = {&PORTC, &PORTB, &PORTB};
uint8_t led_pins[3] = {PORTC4, PORTB4, PORTB5};

void sensor_init()
{	
	for (uint8_t i = 0; i < 3; i++)
		*led_ddrs[i] |= 1 << led_pins[i]; //set led_pins as output

	DDRC &= ~(1 << LDR_PIN); // set LDR_PIN as a input pin

	ADMUX |= (1 << REFS0); //REFS = 1 : External 5V voltage with cpasitor in AREF pin
	
	ADCSRA |= (1 << ADEN) | (1 << ADPS0) | (1 << ADPS1) | (1 << ADPS2); // Enable ADC,	Frequency is 125kHz	
		
	DIDR0 = (1 << LDR_PIN); // Digital input buffer is disabled
}
uint16_t _adc_read(uint8_t pin)
{
	pin &= 0b111; // convert pin value to binary

	ADMUX |= pin; // Initialize pin which is going to ADC (active the pin which we are going top get analog reading)

	ADCSRA |= (1 << ADSC); // begin the ADC

	// delay the function till ADC complete (ADSC = 1 until ADC circule complete)
	while (ADCSRA & (1 << ADSC));	

	return (ADC); // return ADC value
}

void sensor_read(uint16_t *reading)
{
	lcd_clear();
	lcd_set_cursor(0,0);
	lcd_string("Reading");
	for (int i = 0; i < 3; i++)
	{
		*led_ports[i] |= 1 << led_pins[i];	  // Turn on LED
		lcd_char('.');
		_delay_ms(2000);					  // Wait until LDR reading is stable
		reading[i] = _adc_read(LDR_PIN);	  // Get LDR reading (corresponding function in sensor.c)
		*led_ports[i] &= ~(1 << led_pins[i]); // Turn off LED
	}										  // LED pins ---> RED = C4 / GREEN = B4 / BLUE = B2
	
}

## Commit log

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2021-04-26 swap Red and Green pins
    [sensor.ino]
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2021-05-04 Calibration data
    [Data sheet.xlsx]
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2021-05-28 check with L dataset
    [Data sheet.csv, Data sheet.xlsx]
2021-05-28 draw graphs
    [Data sheet.csv, Data sheet.xlsx]
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2021-06-01 Calibrated data
    [Data sheet.xlsx]
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2021-06-02 fix sensor core ref type bug
    [main.c, sensor.c]
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2021-06-02 init altium PCB project
    [RGB_PCB.PrjPcb, Sheet1.SchDoc]
2021-06-04 Import Components to PCB
    [PCB1.PcbDoc, RGB_PCB.PrjPcb, Sheet1.SchDoc]
2021-06-04 Excahnge C2 and C3 designator
    [Sheet1.SchDoc]
2021-06-04 Resize the room to 9x11 cm
    [PCB1.PcbDoc]
2021-06-04 Change Xtal
    [Sheet1.SchDoc]
2021-06-04 Add headers to ISP interface
    [Sheet1.SchDoc]
2021-06-04 Place XTAL
    [PCB1.PcbDoc]
2021-06-04 Import ISP headers
    [PCB1.PcbDoc]
2021-06-05 import schematic to PCB
    [PCB1.PcbDoc, Sheet1.SchDoc]
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2021-06-05 Implemnet single pwm pin
    [Sheet1.SchDoc]
2021-06-05 LDR stability testing Arduino code
    [Data sheet.xlsx]
2021-06-05 Restructre the branch
    [Data sheet.xlsx]
2021-06-05 Sensor testing data set
    [Data sheet.xlsx]
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2021-06-05 changed gitignore file
    [model_1.SLDPRT]
2021-06-05 enclosure - skech of model_01
    [model_01.SLDPRT]
2021-06-06 Add pads for single pwm
    [Sheet1.SchDoc]
2021-06-06 Revert Point1
    [PCB1.PcbDoc]
2021-06-06 revert point 2
    [PCB1.PcbDoc]
2021-06-06 Revert point 3
    [PCB1.PcbDoc]
2021-06-06 fineshed keypad port
    [PCB1.PcbDoc]
2021-06-06 Restructure enclosure folder
    [model_01.SLDPRT]
2021-06-06 Enclosure - Model 2 upper part
    [Model_2_upper.SLDPRT]
2021-06-06 Enclosure - Model 2 middle part
    [Model_2_middle.SLDPRT]
2021-06-06 Enclosure - Model 2 assembly (upper + middle)
    [model_2_assembly(up+mid).SLDASM]
2021-06-07 Change caps
    [PCB1.PcbDoc, RGB_PCB.PrjPcb, Sheet1.SchDoc]
2021-06-07 Only 2 wires left
    [RGB_PCB.PrjPcb]
2021-06-07 finshe routing
    [PCB1.PcbDoc, Sheet1.SchDoc]
2021-06-07 Fix rule violations
    [PCB1.PcbDoc, Sheet1.SchDoc]
2021-06-08 Making a integrated lib with 3D objects for connectors
    [HDR1X1.STEP, HDR1X2.STEP, HDR1X4.STEP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]
2021-06-08 update 3d boides of resitors
    [PCB1.PcbDoc, PCB1.step, Sheet1.SchDoc]
2021-06-08 add 3D bodies to headers and caps
    [PCB1.PcbDoc, Sheet1.SchDoc]
2021-06-09 enclosure - Sensor model 01 lower part
    [sensor_model_1_p1.SLDPRT]
2021-06-09 enclosure - Sensor model 01 upper part
    [sensor_model_1_p2.SLDPRT]
2021-06-09 enclosure - sensor model 1 full assembly
    [Sensor_full.SLDASM]
2021-06-11 create color sheet for dataset3
    [dataset3.2.csv, dataset3.csv, dataset3.xlsx]
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2021-06-12 Add power regulator
    [PCB1.PcbDoc, RGB_PCB.PrjPcb, Sheet1.SchDoc]
2021-06-12 Fix unroute error
    [PCB1.PcbDoc]
2021-06-13 format top overlay
    [Sheet1.SchDoc]
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2021-06-13 lcd command function error correction
    [keypad.c, main.c]
2021-06-14 add jumpers
    [PCB1.PcbDoc, Sheet1.SchDoc]
2021-06-14 body model 01
    [model_1.SLDPRT]
2021-06-14 body - model 02 upper part
    [Model_2_upper.SLDPRT]
2021-06-14 body - model 02 middle part
    [Model_2_middle.SLDPRT]
2021-06-14 body - model 02 Assembly(upper + middle)
    [model_2_assembly(up+mid).SLDASM]
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2021-06-14 body - add sensor holderand border cuts
    [Model_2_middle.SLDPRT, Model_2_upper.SLDPRT]
2021-06-15 STEP AP214 files of each parts
    [Model_2_middle_stp.STEP, Model_2_upper_stp.STEP, model_2_assembly(up+mid)_stp.STEP]
2021-06-16 add embossed group name
    [21A_upper.SLDPRT]
2021-08-03 add quick view pcb files
    [PCB1.PcbDoc, RGB_PCB.PrjPcb]
2021-08-03 crate a backup of PCB
    [PCB1.PcbDoc, RGB_PCB.PrjPcb, Sheet1.SchDoc]
2021-08-03 add single-pwm shematic
    [RGB_PCB.PrjPcb, single-pwm.SchDoc]
2021-08-04 modify pcb for single pwm only
    [PCB1.PcbDoc, Sheet1.SchDoc]
2021-08-04 set label orientaion
    [PCB1.PcbDoc]
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2021-08-06 set alignment schematic
    [Sheet1.SchDoc]
2021-08-06 create pcb pdfs
    [PCB1.PcbDoc, RGB_PCB.PrjPcb, Sheet1.SchDoc]
2021-08-07 create 3 pwm pins backup
    [PCB1.PcbDoc, Sheet1.SchDoc]
2021-08-07 add screw hole to top right
    [PCB1.PcbDoc, Sheet1.SchDoc]
2021-08-07 finalze screw hole positions
    [PCB1.PcbDoc]
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2021-08-07 add a step file
    [middle_part_from_step.SLDPRT]
2021-08-07 place screw holes symetricly
    [PCB1.PcbDoc]
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2021-08-07 re-route lcd port wires
    [PCB1.PcbDoc]
2021-08-08 add external parts
    [LCDScreen.SLDPRT, Matrix Keypad 12 Key (4X3).SLDPRT, Matrix Keypad 12 Key (4X3).STEP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]
2021-08-08 add external parts to design
    [BATTARY HOLDER.SLDPRT, BATTARY HOLDER.STEP, Batterie 9V.IGS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]
2021-08-08 add rgb led and push button
    [2_pin_push_button.SLDPRT, BATTARY HOLDER.SLDPRT, CA GRB LED 5mm.SLDPRT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]
2021-08-09 add screws
    [bottom_part.SLDPRT, rgb_led.SLDPRT]
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2021-08-10 clean pcb branch
    [HDR1X1.STEP, HDR1X2.STEP, HDR1X4.STEP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]
2021-08-10 align reset port
    [PCB1.PcbDoc]
2021-08-10 connect sensor with wire
    [Jumper.SLDASM, Jumper.SLDASM.3.x_t, Jumper.iges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]
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2021-08-10 create sensor pcb step file
    [PCB_Sensor.step]
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2021-08-10 add 3D bodies to library
    [HDR1X1.STEP, HDR1X2.STEP, HDR1X4.STEP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]
2021-08-10 fix violations of pcb sensor
    [PCB_Main.PcbDoc, RGB_PCB.PrjPcb]
2021-08-10 step file for cap
    [Cap3.STEP]
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2021-08-10 flip leds and ldr in sensor pcb
    [PCB_Sensor.PcbDoc, PCB_Sensor.step, RGB_PCB.PrjPcb]
2021-08-11 add wires to led and push button
    [rgb.SLDPRT, rgb_led.SLDPRT]
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2021-08-11 add 3d boides for cap and power port
    [PCB_Main.PcbDoc, PCB_Sensor.step, RGB_PCB.PrjPcb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]
2021-08-11 elevate LEDs in sensor 3D pcb
    [PCB_Sensor.PcbDoc, PCB_Sensor.step]
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2021-08-12 add capacitors and power jack
    [PCB_Sensor (2).step, Sensor_Top.STEP, Sensor_full (1).STEP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]
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2021-08-12 add missed componenets
    [10pF Ceramic Disc 2.SLDPRT, LCDScreen.SLDPRT, Matrix Keypad 12 Key (4X3).SLDPRT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]
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
